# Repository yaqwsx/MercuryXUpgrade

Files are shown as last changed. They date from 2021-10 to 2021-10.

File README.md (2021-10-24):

# Marcury X Upgrade

Upgrades for Elegoo Mercury X Bundle Washing and curing machine. Currently
includes:

- a second cleaning container made out of IKEA 365 food container.

Be sure to read the orignal post before building: [Hand-on experiences with
Mercury X Washing & Curing station and 15 USD must-have
upgrades](https://blog.honzamrazek.cz/2021/10/hand-on-experiences-with-mercury-x-washing-curing-station-and-15-usd-must-have-upgrades/).

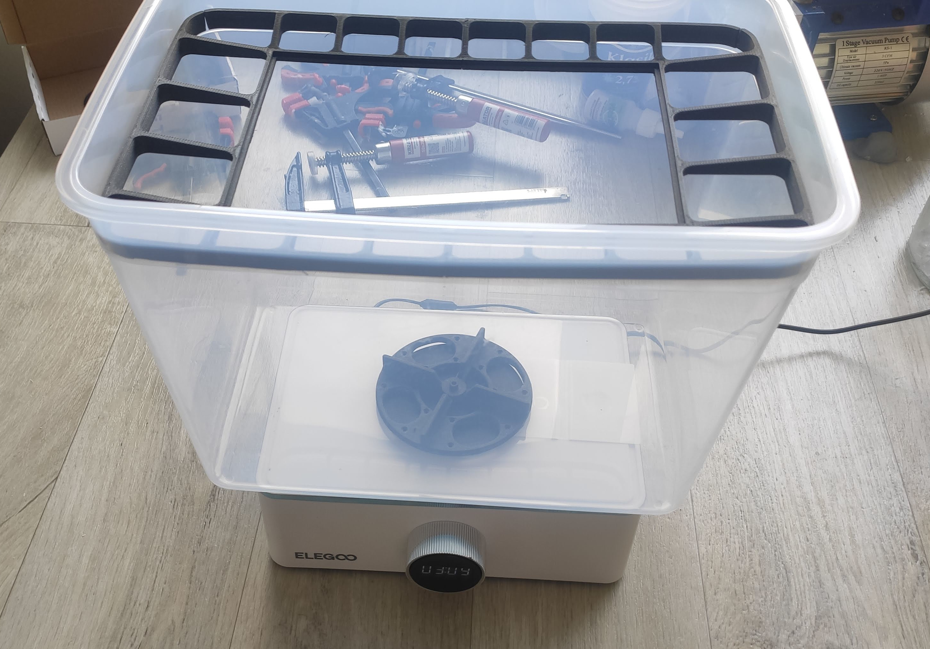
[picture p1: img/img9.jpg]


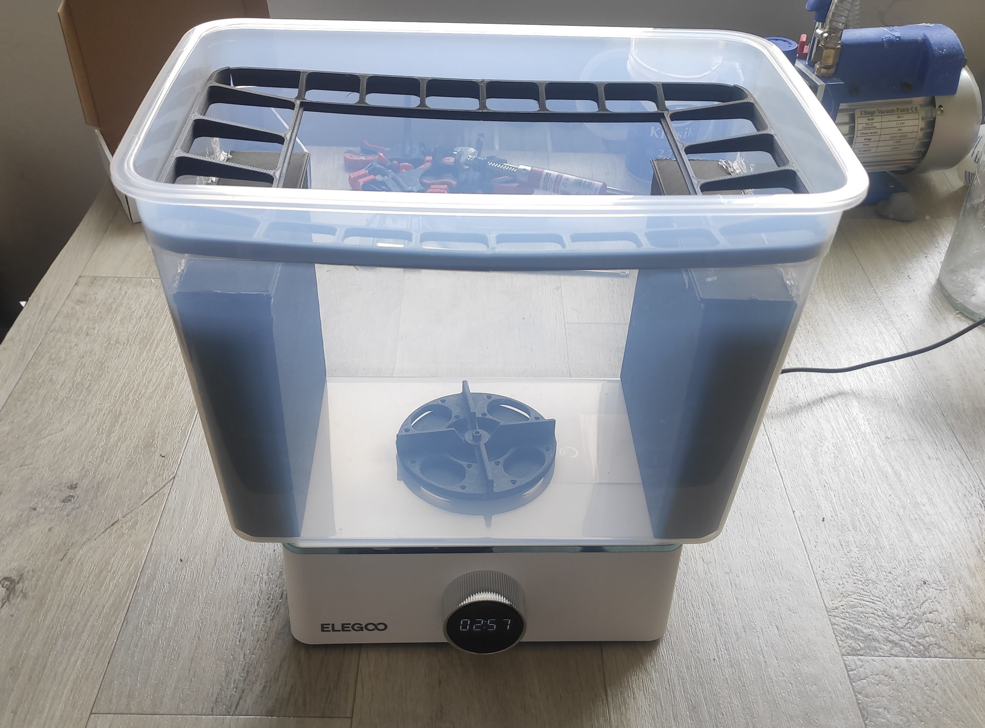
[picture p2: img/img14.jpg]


# How to build?

See individual guide pages. These pages include bill of materials and step-by-step
guides for building.

- [build the extra container](guides/extraContainer.md)

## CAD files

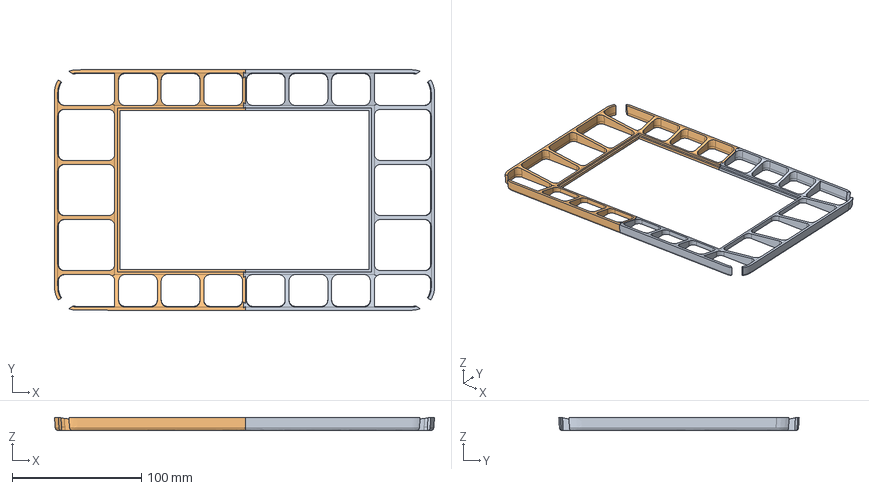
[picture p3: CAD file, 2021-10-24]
models/BuildPlateStand.step
294.3 x 186.3 x 10.0 mm

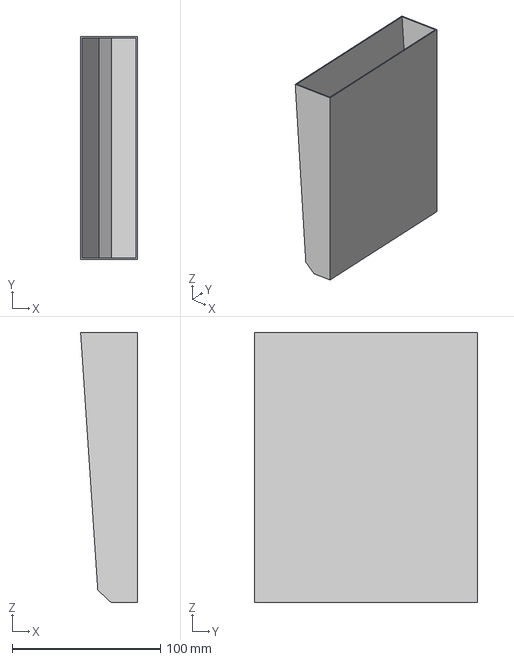
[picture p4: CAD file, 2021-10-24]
models/ballast.step
38.3 x 150.0 x 182.0 mm

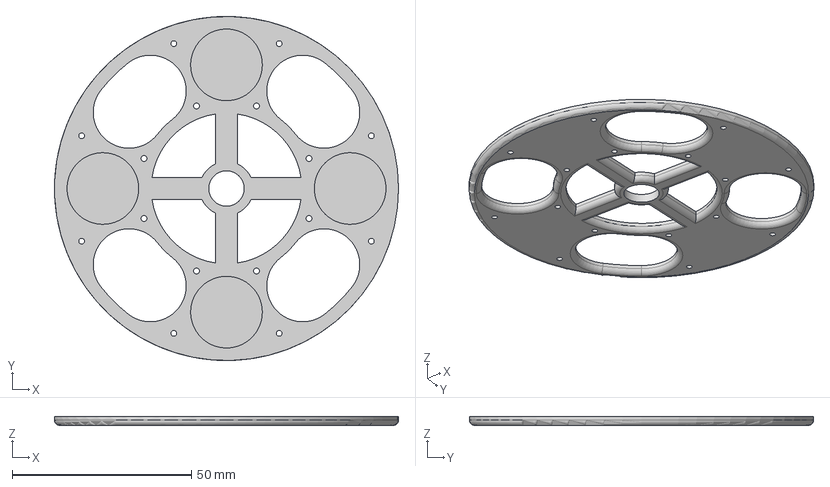
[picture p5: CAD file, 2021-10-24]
models/impellerBottom.step
96.0 x 96.0 x 2.50 mm

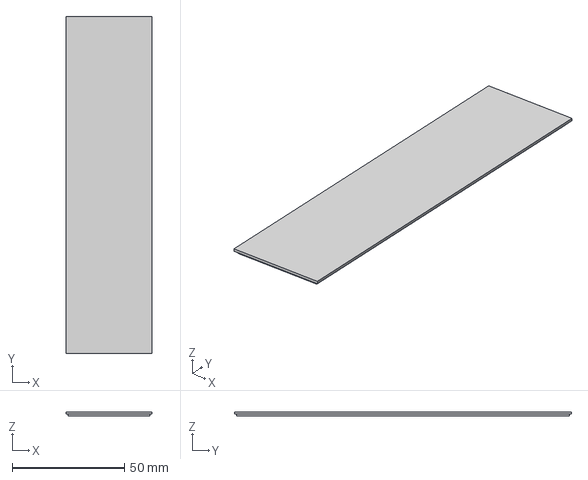
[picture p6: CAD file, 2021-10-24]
models/cover.step
38.3 x 150.0 x 2.00 mm

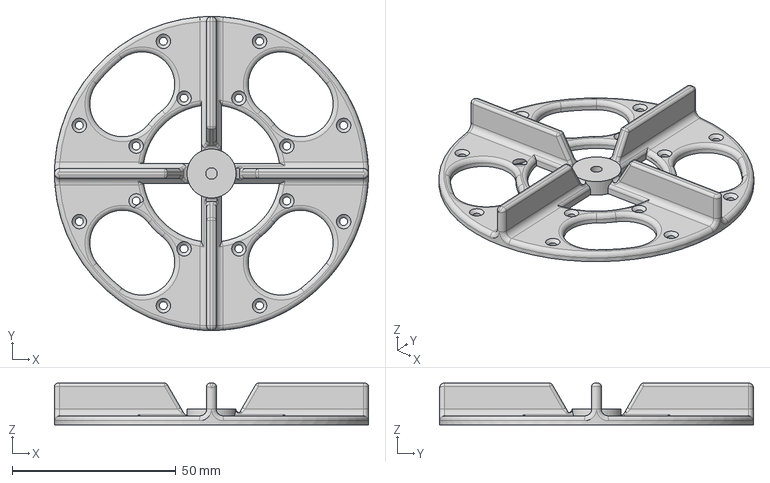
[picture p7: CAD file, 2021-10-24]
models/impellerTop.step
96.0 x 96.0 x 12.8 mm

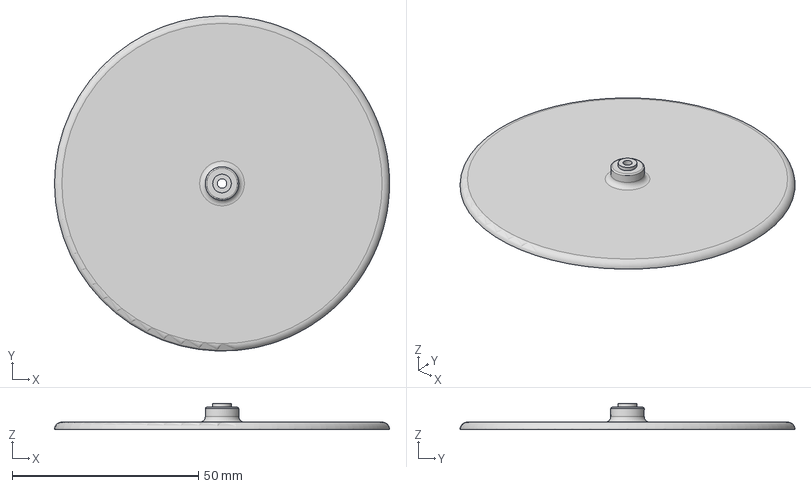
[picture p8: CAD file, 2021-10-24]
models/impellerHub.step
90.0 x 90.0 x 7.00 mm

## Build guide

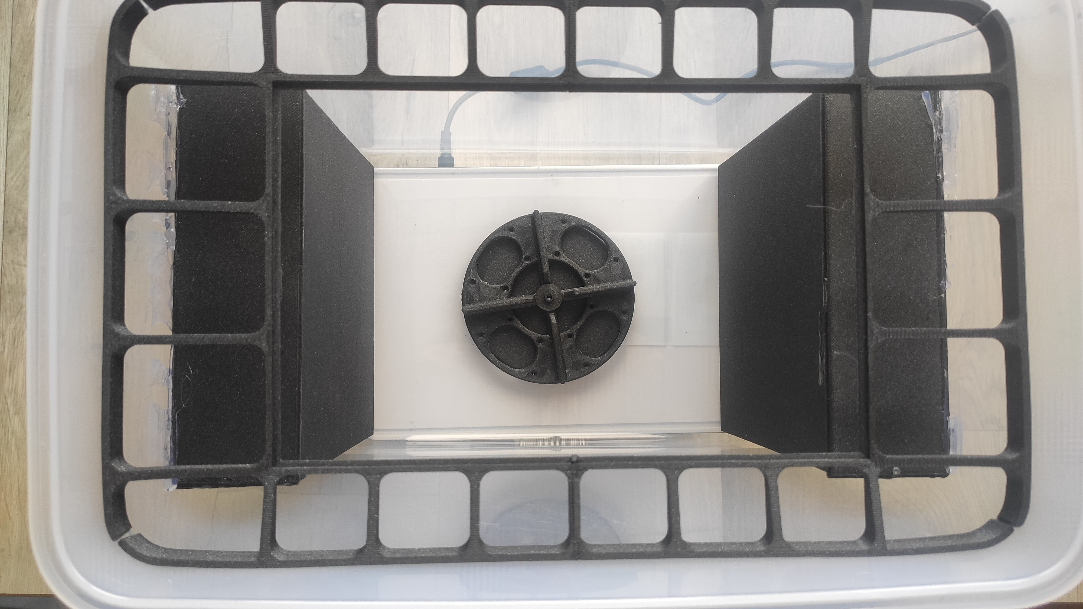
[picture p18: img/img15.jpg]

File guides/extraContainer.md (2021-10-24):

# Extra container

## Bill of materials

- 1pcs [IKEA 365+ 10.6l container](https://www.ikea.com/cz/en/p/ikea-365-food-container-with-lid-rectangular-plastic-s79276760/)
- 4pcs [20×2 mm cylindrical neodymium magnets](https://s.click.aliexpress.com/e/_ArYCDr)
- 1pcs M3 nut
- 1pcs M3x20 screw

## What to print

- 1pcs [impeller top](../models/impellerTop.step)
- 1pcs [impeller bottom](../models/impellerBottom.step)
- 1pcs [impeller hub](../models/impellerHub.step)
- 1pcs [build plate stand](../models/BuildPlateStand.step) (contains 2 bodies, print
  separately if you don't have large enough machine)
- optionally for ballast to reduce container volume:
    - 2pcs [ballast](../models/ballast.step)
    - 2pcs [ballast](../models/cover.step)

I suggest printing it out of PLA, use 100% infill and use supports for printing
to get a nice pockets for the magnets. I also advise to use 20 perimeters - it
speeds up printing significantly.

## Assembly

These are the component you should print:

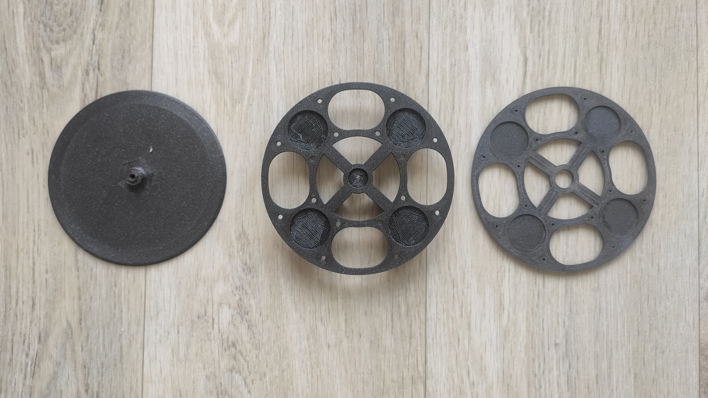
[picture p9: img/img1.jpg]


Start by inserting magnets. Insert them on the machine to ensure correct
orientation (the magnet should stick to the baseplate)

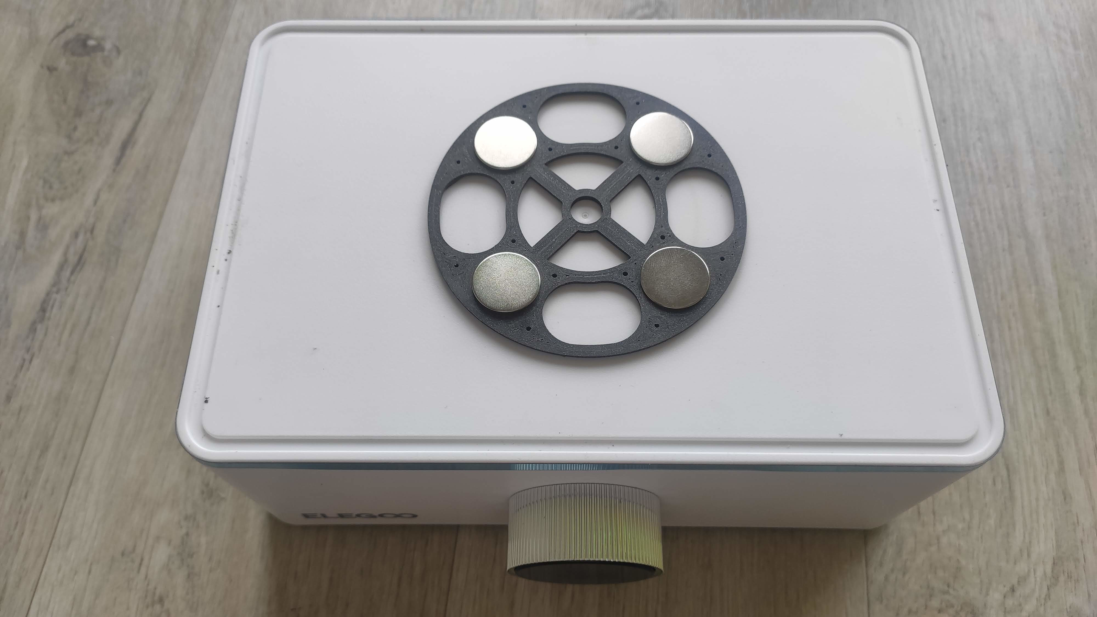
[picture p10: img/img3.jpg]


Then glue the top and bottom parts of the impeller. I suggest using a super glue
or epoxy. If you want to avoid gluing, there are prepared holes for M2 screw
with countersink.

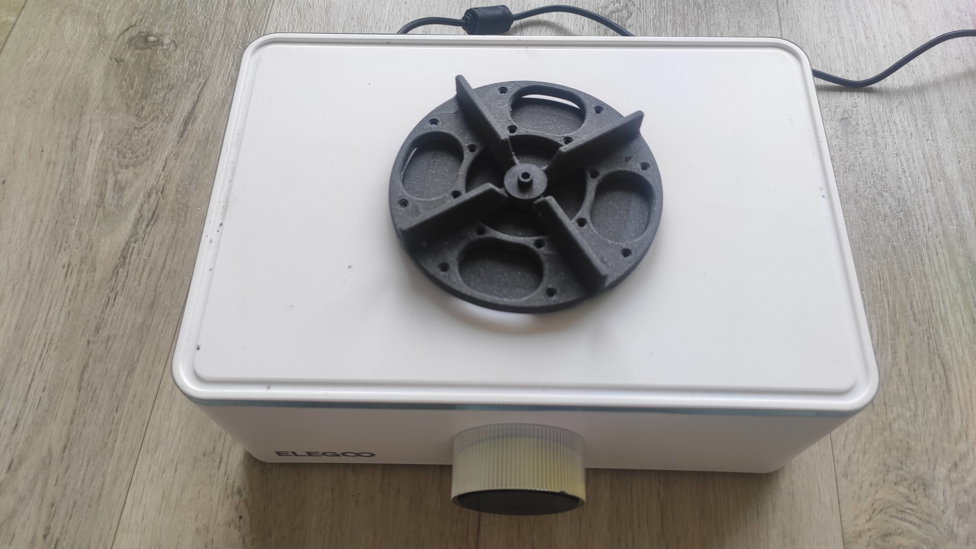
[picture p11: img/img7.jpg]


Next, let's move to the hub. Remove supports from the bottom. Now you can either
tap M3 thread into the base or enlarge the hole slightly and heat press M3 nut:

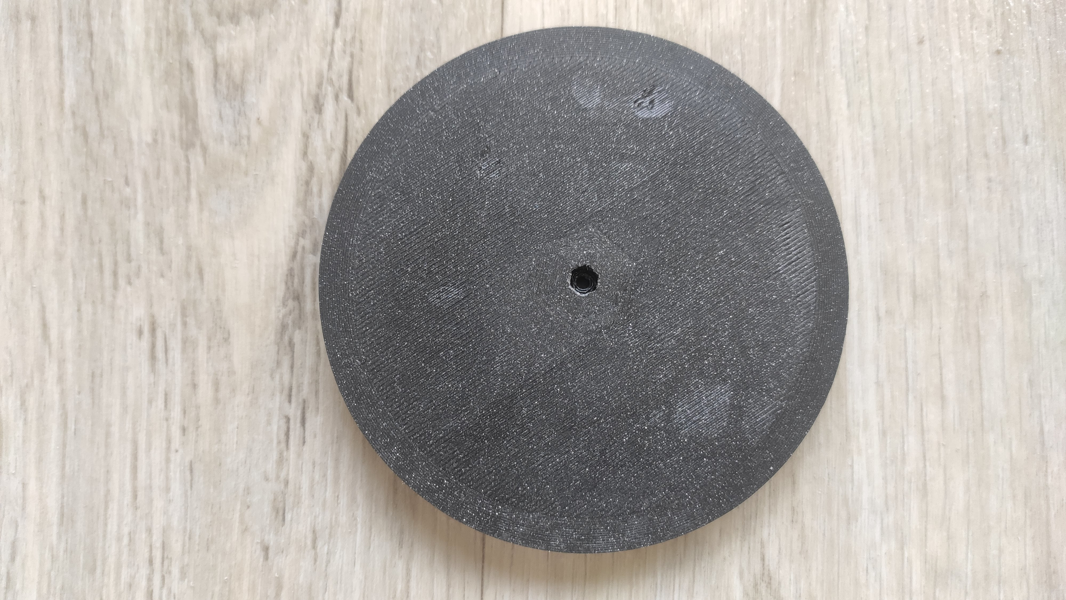
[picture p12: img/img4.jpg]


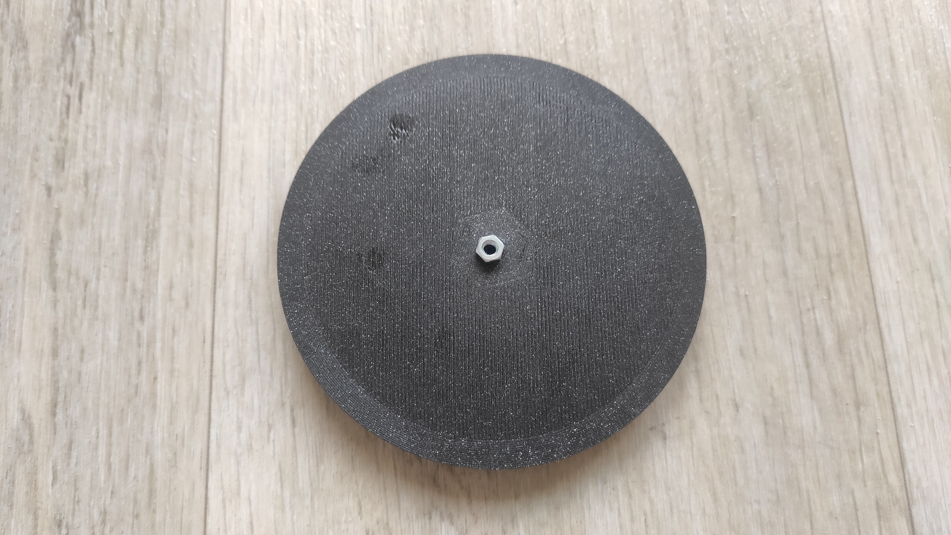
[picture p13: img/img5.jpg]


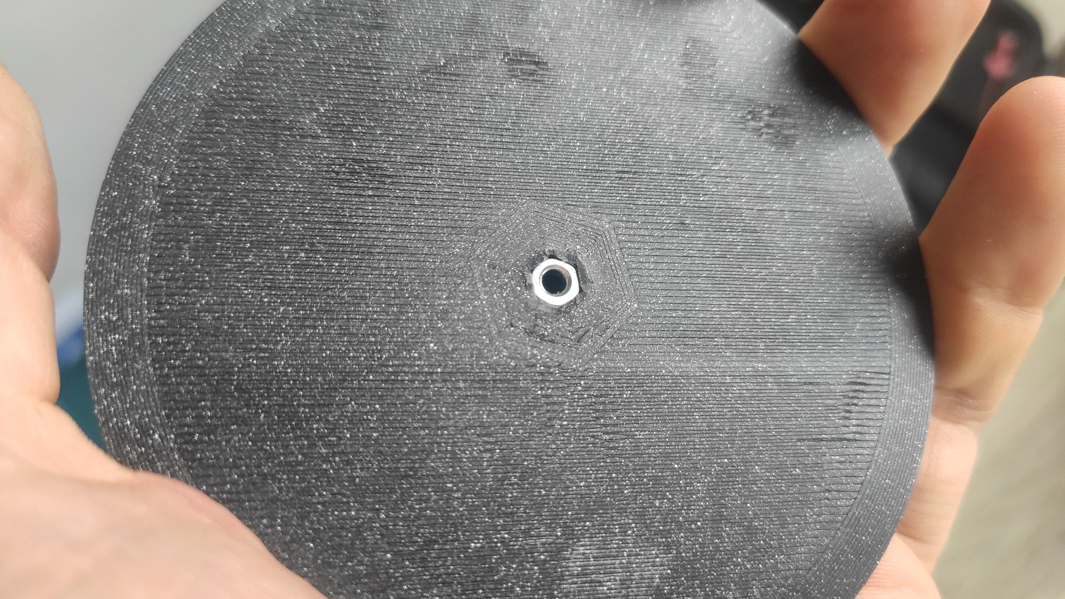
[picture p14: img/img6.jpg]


The build plate stand is designed to firmly pressed together. Once it is
assembled you can put in into the container. It should fit really tightly.

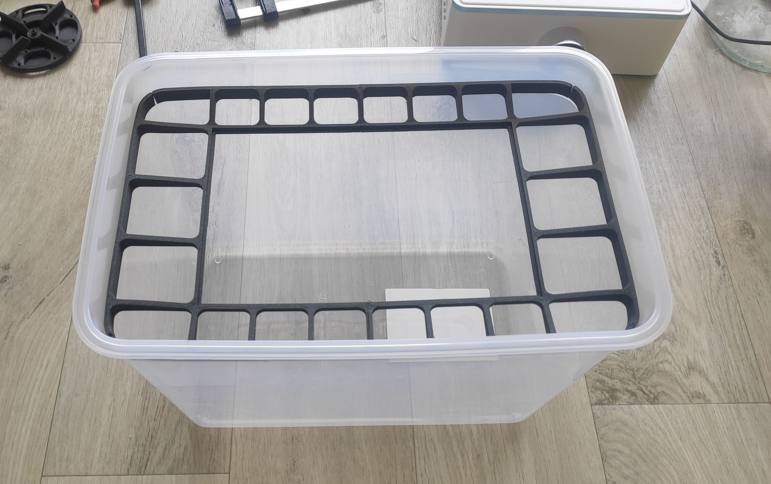
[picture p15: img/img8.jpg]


As the last step, glue the hub to the bottom of the tank. I suggest using a
5-minute epoxy. Once the glue settles, screw in the impeller using M3 screw. Do
not overtight the screw - the impeller has to spin freely.



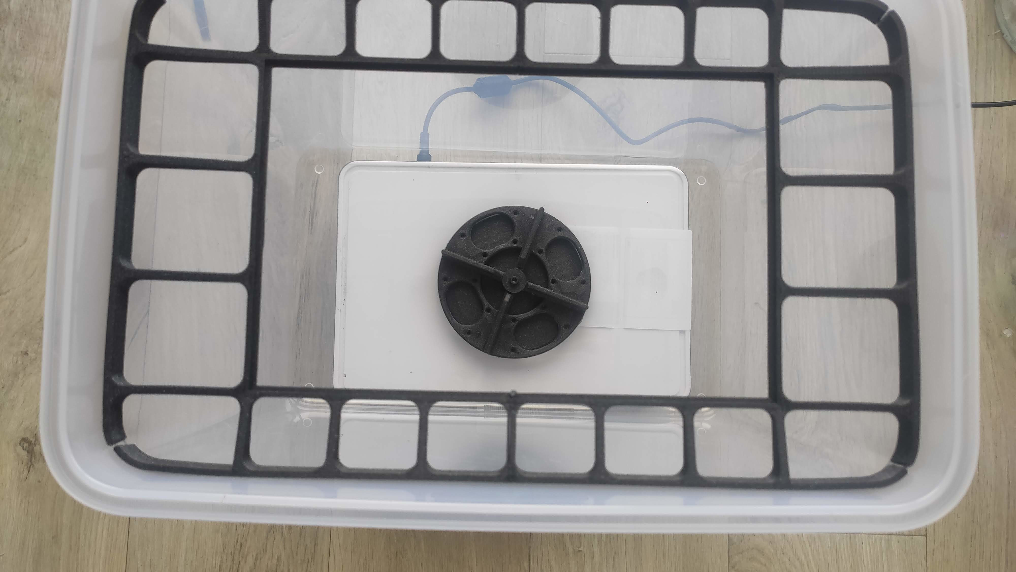
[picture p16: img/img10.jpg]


Optionally, if you would like to reduce the volume of the tank, print ballast
containers, fill them with sand and properly glue covers. Be sure that the glued
joint is airtight!

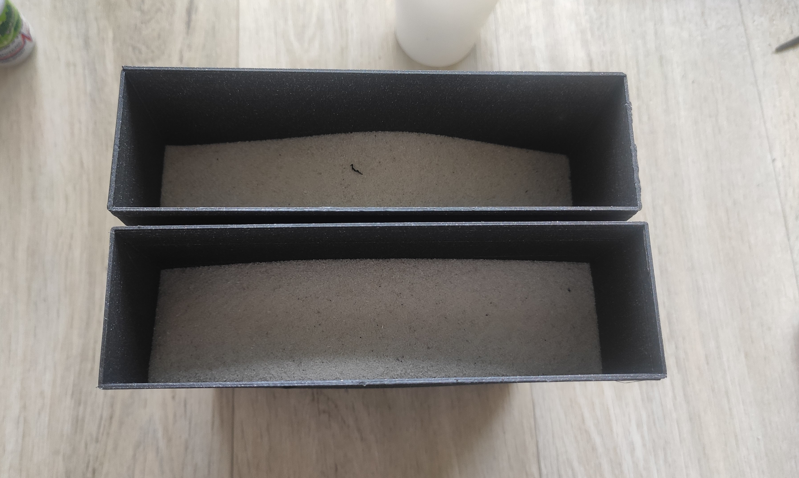
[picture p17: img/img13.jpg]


And then glue them to the walls of the container:
